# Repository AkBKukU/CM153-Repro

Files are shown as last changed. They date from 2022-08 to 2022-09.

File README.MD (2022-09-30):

# Philips CM-153 LMSI Reproduction Card

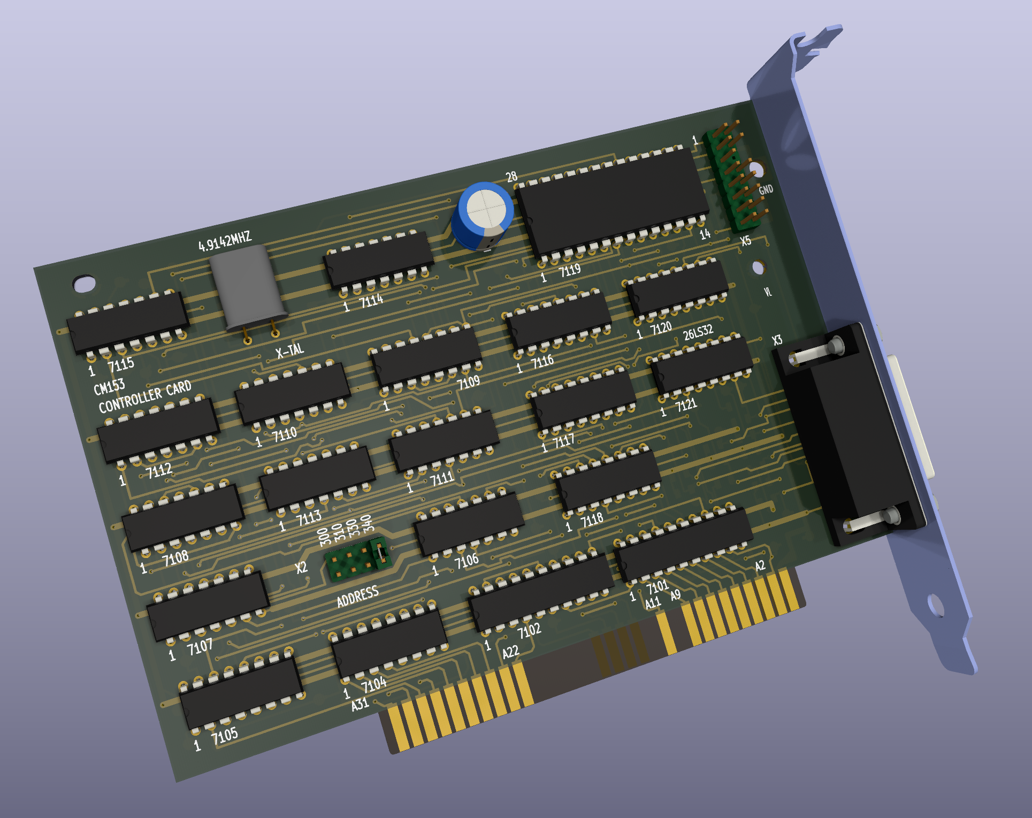
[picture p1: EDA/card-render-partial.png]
A 3d render of the board A render of the clone PCB

 
This project aims to reproduce the LMSI CM-153 card needed to operate a Philips CM-100 CD-ROM drive. This drive was originally released in 1985 and used an early version of the LSMI protocol to connect. Later versions of LMSI cards, such as the CM-260, are not compatible with earlier drives (I do not know what the exactly compatibilities are). So an early card is required. The CM-153 is a very uncommon part to find due to it's limited use, high cost, and the fact that it would probably be tossed out with the computer when upgraded being separated from its original drive.

Thanks to Roland who has a [working CM-100 and CM-153](https://www.youtube.com/watch?v=fj-uSWg0LOY) we have some pretty high quality reference images of what this card looks like. It uses all off the shelf 74 series logic chips and one 8251A UART controller. It should therefore be possible to recreate without needing any rare chips or ROM dumps.

## Current Status

The card has been fully reverse engineered and tested to be functional. It has been demonstrated to work using [this](http://mpolibbs.steptail.com/hardware/CDROM/PHILIPS/CM50DRV.ZIP) driver with a CM100 drive.

## Notes

A more acurate build will put 7121 in a socket as it must be removed to use the card with an internal drive. If you just want to use it with an external drive this can be ommited.

The selected DB-15 connector doesn't include the screw nuts which can be purchased separately.

## Parts List

*(Parts picked on 2022-09-07 and reflected best available stock)*

|RefDes|Original Part Number| Datasheet| Digikey Part| Mouser Part|
--- | --- | ---| ---| ---|
|7101|PC74HCT245P|[Datasheet](https://assets.nexperia.com/documents/data-sheet/74HC_HCT245.pdf)|[CD74HCT245E](https://www.digikey.com/en/products/detail/texas-instruments/CD74HCT245E/38454)|[SN74HCT245NE4](https://www.mouser.com/ProductDetail/Texas-Instruments/SN74HCT245NE4?qs=SL3LIuy2dWzrNeCJprt44g%3D%3D)|
|7102|PC74HCT244P|[Datasheet](https://assets.nexperia.com/documents/data-sheet/74HC_HCT244.pdf)|[CD74HCT244E](https://www.digikey.com/en/products/detail/texas-instruments/CD74HCT244E/38450)|[CD74HCT244E](https://www.mouser.com/ProductDetail/Texas-Instruments/CD74HCT244E?qs=Zu35EjizYSQlHH5t78bA9Q%3D%3D)|
|7104,7105|PC74HCT138P|[Datasheet](https://archive.org/details/74HCT138)|[CD74HCT138E](https://www.digikey.com/en/products/detail/texas-instruments/CD74HCT138E/38262)|[CD74HCT138E](https://www.mouser.com/ProductDetail/Texas-Instruments/CD74HCT138E?qs=IEl3ej0IqwCH%2FZM9hy22Dg%3D%3D)|
|7106|PC74HC08P|[Datasheet](https://archive.org/details/manuallib-id-2654066)|[TC74HC08APF](https://www.digikey.com/en/products/detail/toshiba-semiconductor-and-storage/TC74HC08APF/870461)|[SN74HC08AN](https://www.mouser.com/ProductDetail/Texas-Instruments/SN74HC08AN?qs=byeeYqUIh0O9MyGywGYg%252Bw%3D%3D)|
|7107,7108|PC74HC32P|[Datasheet](https://assets.nexperia.com/documents/data-sheet/74HC_HCT32.pdf)|**!M!**[NTE74HC32](https://www.digikey.com/en/products/detail/nte-electronics-inc/NTE74HC32/11650138)|[SN74HC32N](https://www.mouser.com/ProductDetail/Texas-Instruments/SN74HC32N?qs=tJ5HNKWh3OWs99bm2e8RtQ%3D%3D)|
|7109|PC74HC368P|[Datasheet](https://assets.nexperia.com/documents/data-sheet/74HC_HCT368.pdf)|[SN74HC368N](https://www.digikey.com/en/products/detail/texas-instruments/SN74HC368N/376786)|[SN74HC368N](https://www.mouser.com/ProductDetail/Texas-Instruments/SN74HC368N?qs=7KMwW2o1%252BmQFMEJMMaje4Q%3D%3D)|
|7110|PC74HC04P|[Datasheet](https://assets.nexperia.com/documents/data-sheet/74HC_HCT04.pdf)|[SN74HC04N](https://www.digikey.com/en/products/detail/texas-instruments/SN74HC04N/277212)|[SN74HC04AN](https://www.mouser.com/ProductDetail/Texas-Instruments/SN74HC04AN?qs=byeeYqUIh0N6S9uYkR6RCw%3D%3D)|
|7111|PC74HC125P|[Datasheet](https://assets.nexperia.com/documents/data-sheet/74HC_HCT125.pdf)|[CD74HC125E](https://www.digikey.com/en/products/detail/texas-instruments/CD74HC125E/475901)|[SN74HC125NE4](https://www.mouser.com/ProductDetail/Texas-Instruments/SN74HC125NE4?qs=AgY10sKTvDLokkOrwnzHmA%3D%3D)|
|7112,7113|PC74HC74P|[Datasheet](https://assets.nexperia.com/documents/data-sheet/74HC_HCT74.pdf)|NOT AVAILABLE|[CD74HC74EE4](https://www.mouser.com/ProductDetail/Texas-Instruments/CD74HC74EE4?qs=xFfolx0DHx2A6AZK2ZbvuQ%3D%3D)|
|7114,7115|PC74HC4024P|[Datasheet](https://assets.nexperia.com/documents/data-sheet/74HC4024.pdf)|[CD74HC4024E](https://www.digikey.com/en/products/detail/texas-instruments/CD74HC4024E/376737)|[CD74HC4024E](https://www.mouser.com/ProductDetail/Texas-Instruments/CD74HC4024E?qs=pt%2FIv5r0EPeVxf9RvRS8Kg%3D%3D)|
|7116,7117,7118|MC74HC595AN|[Datasheet](https://assets.nexperia.com/documents/data-sheet/74HC_HCT595.pdf)|[CD74HC595E](https://www.digikey.com/en/products/detail/texas-instruments/CD74HC595E/1507396)|[SN74HC595NE4](https://www.mouser.com/ProductDetail/Texas-Instruments/SN74HC595NE4?qs=AgY10sKTvDK0jki9CKjSwg%3D%3D)|
|7119|P8251A|[Datasheet](http://map.grauw.nl/resources/midi/intel_8251.pdf)|NOT AVAILABLE|NOT AVAILABLE|
|7120|DS26LS31CN|[Datasheet](https://www.ti.com/lit/ds/symlink/am26ls31.pdf)|NOT AVAILABLE|[AM26LS31CN](https://www.mouser.com/ProductDetail/Texas-Instruments/AM26LS31CN?qs=mTHRaKC2c7NO%252BlWH6D4lHg%3D%3D)|
|7121|DS26LS32CN|[Datasheet](https://www.ti.com/lit/ds/symlink/am26ls32am.pdf)|[AM26LS32ACN](https://www.digikey.com/en/products/detail/texas-instruments/AM26LS32ACN/277026)|[AM26LS32ACN](https://www.mouser.com/ProductDetail/Texas-Instruments/AM26LS32ACN?qs=IF4wzcbwb3oK65Lb3k1iHg%3D%3D)|
|X-TAL|4.9152MHz||[MP042](https://www.digikey.com/en/products/detail/cts-frequency-controls/MP042/67676)|[MP042](https://www.mouser.com/ProductDetail/CTS-Electronic-Components/MP042?qs=Mr%252BgrRYddfqYTabPpjTZhQ%3D%3D)|
|Big cap (C9)|50V 10uF||[ECA-1HHG100B](https://www.digikey.com/en/products/detail/panasonic-electronic-components/ECA-1HHG100B/413608)|[ECA-1HHG100B](https://www.mouser.com/ProductDetail/Panasonic/ECA-1HHG100B?qs=86KMePBwEH3eLbQCzM6gng%3D%3D)|
|X5|2x8 pin IDC||2x [826656-2](https://www.digikey.com/en/products/detail/te-connectivity-amp-connectors/826656-2/2276228)|2x [826656-2](https://www.mouser.com/ProductDetail/TE-Connectivity/826656-2?qs=DbJIyW2JsP7yZR%252BsE22lHg%3D%3D)|
|X2|2x4 pin IDC||[826656-2](https://www.digikey.com/en/products/detail/te-connectivity-amp-connectors/826656-2/2276228)|[826656-2](https://www.mouser.com/ProductDetail/TE-Connectivity/826656-2?qs=DbJIyW2JsP7yZR%252BsE22lHg%3D%3D)|
|Y3|15 pin D-Sub||[D15S13B4GX00LF](https://www.digikey.com/en/products/detail/amphenol-cs-fci/D15S13B4GX00LF/1539503)|[D15S13B4GX00LF](https://www.mouser.com/ProductDetail/Amphenol-FCI/D15S13B4GX00LF?qs=V0y2QjpmBGTkGk8fxG40%2FA%3D%3D)|
|C1, C2, C3, C8|100nF||[C1206C104K5RAC7800](https://www.digikey.com/en/products/detail/kemet/C1206C104K5RAC7800/411248)|[C1206C104K5RAC](https://www.mouser.com/ProductDetail/KEMET/C1206C104K5RAC?qs=utjsALNw%2FXTrbYrRGHNW%2Fw%3D%3D)|
|C4|33pF||[885012008020](https://www.digikey.com/en/products/detail/w%C3%BCrth-elektronik/885012008020/5453728)|[885012008020](https://www.mouser.com/ProductDetail/Wurth-Elektronik/885012008020?qs=0KOYDY2FL291ofVgKwDyIQ%3D%3D)|
|C5, C6|14pF||[885012008038](https://www.digikey.com/en/products/detail/w%C3%BCrth-elektronik/885012008038/5453737)|[885012008038](https://www.mouser.com/ProductDetail/Wurth-Elektronik/885012008038?qs=0KOYDY2FL2%252BQ%252BIYq9i7pEA%3D%3D)|
|C7|47pF||[885012008021](https://www.digikey.com/en/products/detail/w%C3%BCrth-elektronik/885012008021/5453729)|[885012008021](https://www.mouser.com/ProductDetail/Wurth-Elektronik/885012008021?qs=0KOYDY2FL2%2F%252Bm93ZHe2ewg%3D%3D)|
|R1|10KΩ||[RMCF1206JT10K0](https://www.digikey.com/en/products/detail/stackpole-electronics-inc/RMCF1206JT10K0/1757427)|[RC1206FR-1310KL](https://www.mouser.com/ProductDetail/YAGEO/RC1206FR-1310KL?qs=sGAEpiMZZMvdGkrng054t8AJgcdMkx7xV9EP%2FUfQrjQ%3D)|
|R2|1MΩ||[HV73V2BTTD105J](https://www.digikey.com/en/products/detail/koa-speer-electronics-inc/HV73V2BTTD105J/11495356)|[RC1206JR-071ML](https://www.mouser.com/ProductDetail/YAGEO/RC1206JR-071ML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)|
|R3|100Ω||[RNCP1206FTD100R](https://www.digikey.com/en/products/detail/stackpole-electronics-inc/RNCP1206FTD100R/2240316)|[RC1206JR-07100RL](https://www.mouser.com/ProductDetail/YAGEO/RC1206JR-07100RL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)|
|R4|1KΩ||[RMCF1206JT1K00](https://www.digikey.com/en/products/detail/stackpole-electronics-inc/RMCF1206JT1K00/1757526)|[RC1206FR-131KL](https://www.mouser.com/ProductDetail/YAGEO/RC1206FR-131KL?qs=sGAEpiMZZMvdGkrng054t8AJgcdMkx7xEX6WAGFcbHI%3D)|
|R5, R6, R7, R8|120Ω||[RMCF1206JT120R](https://www.digikey.com/en/products/detail/stackpole-electronics-inc/RMCF1206JT120R/1757405)|[RC1206FR-07120RL](https://www.mouser.com/ProductDetail/YAGEO/RC1206FR-07120RL?qs=sGAEpiMZZMvdGkrng054t8AJgcdMkx7xHngnO2SPVlk%3D)|
|R10, R12, R14, R16|270Ω||[MCR18ERTJ271](https://www.digikey.com/en/products/detail/rohm-semiconductor/MCR18ERTJ271/2796388)|[RC1206FR-07270RL](https://www.mouser.com/ProductDetail/YAGEO/RC1206FR-07270RL?qs=sGAEpiMZZMvdGkrng054t8AJgcdMkx7xeAVb6tXWI0g%3D)|
|R9, R11, R13, R15|220Ω||[RMCF1206JT220R](https://www.digikey.com/en/products/detail/stackpole-electronics-inc/RMCF1206JT220R/1757377)|[AC1206JR-07220RL](https://www.mouser.com/ProductDetail/YAGEO/AC1206JR-07220RL?qs=sGAEpiMZZMvdGkrng054t7zOzNqIRvGc5GFE1pYUTcM%3D)|
|Card Bracket|Bottom DB15 Cutout||[9200-11](https://www.digikey.com/en/products/detail/keystone-electronics/9200-11/2746684)|[9200-11](https://www.mouser.com/ProductDetail/Keystone-Electronics/9200-11?qs=%252BU2dxLPlMC0AIccOWCwv6Q%3D%3D)|

*All SMD parts 1206 size.*

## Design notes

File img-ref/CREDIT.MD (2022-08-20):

Thank you to Roland who has a [working CM-100 and CM-153](https://www.youtube.com/watch?v=fj-uSWg0LOY) for taking these reference images for determining what the chips and other parts on the card are and how the traces are routed!

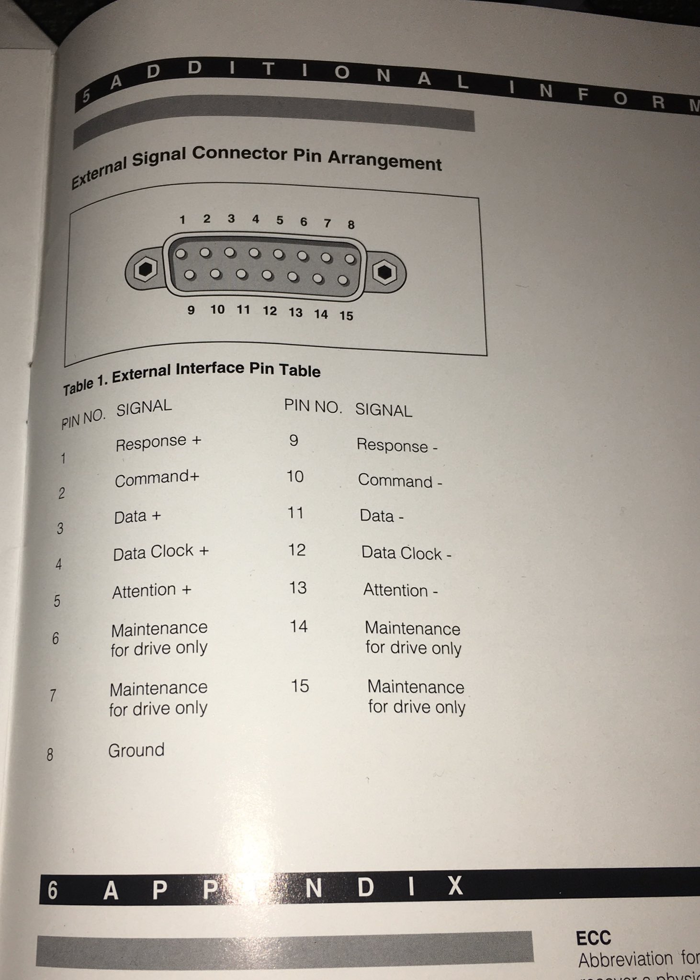
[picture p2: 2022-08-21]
img-ref/LMSI-pinout.jpeg

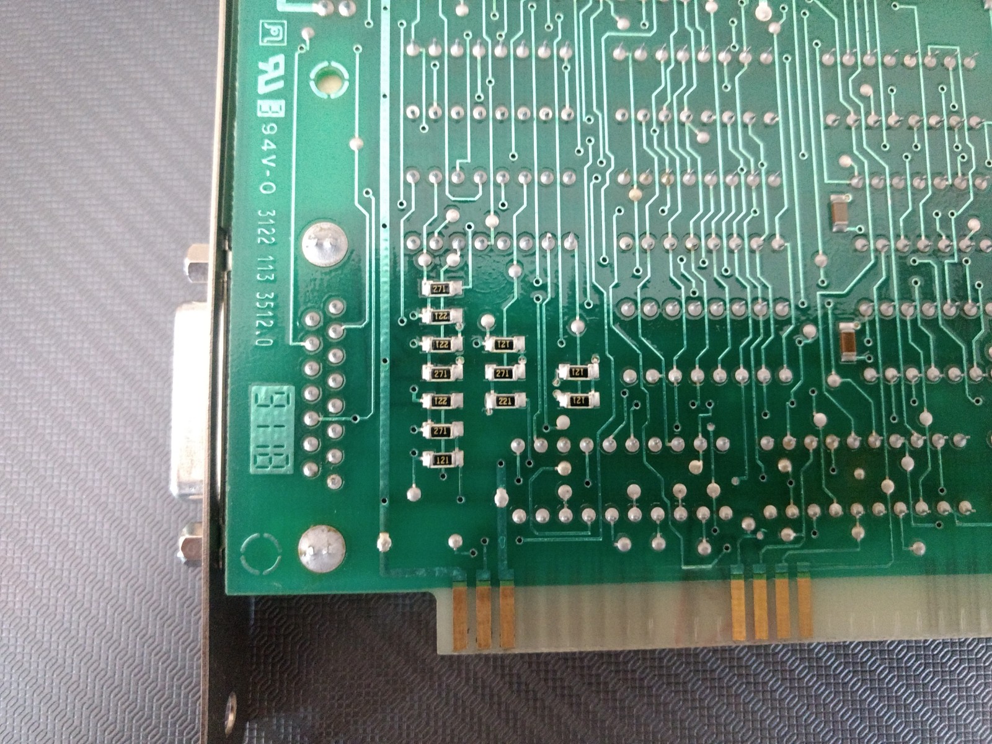
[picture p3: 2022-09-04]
img-ref/diff-rev/resistors.jpeg

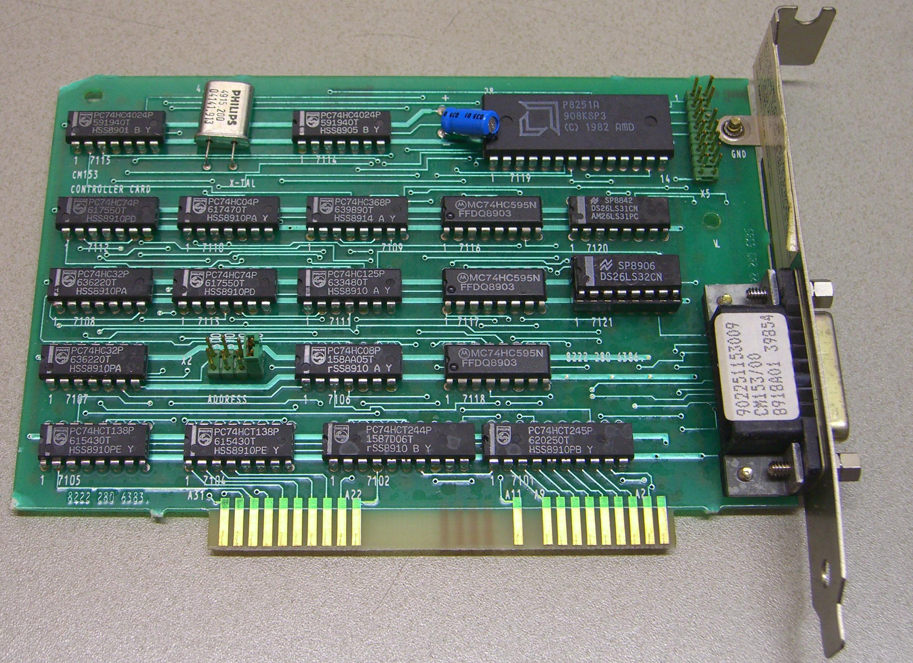
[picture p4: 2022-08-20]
img-ref/CIMG3734.JPG

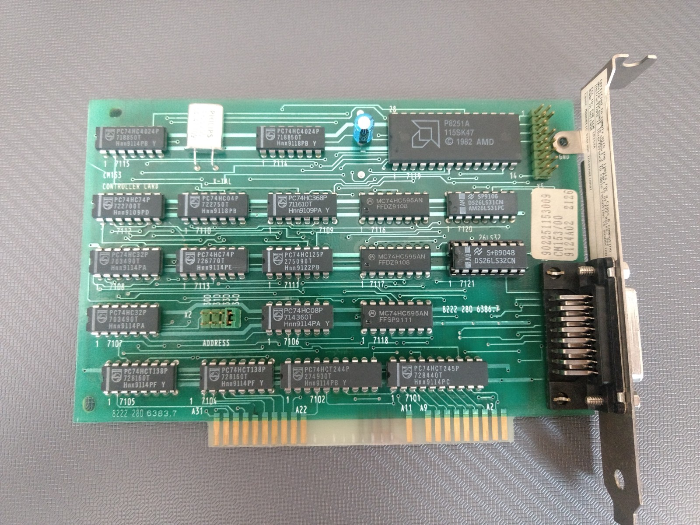
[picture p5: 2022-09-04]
img-ref/diff-rev/front.jpeg

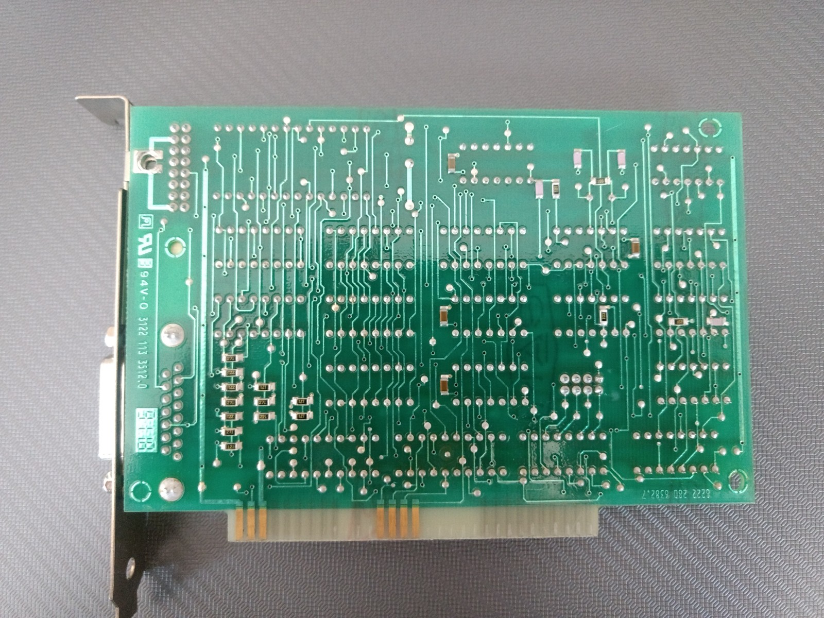
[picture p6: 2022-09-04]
img-ref/diff-rev/bottom.jpeg

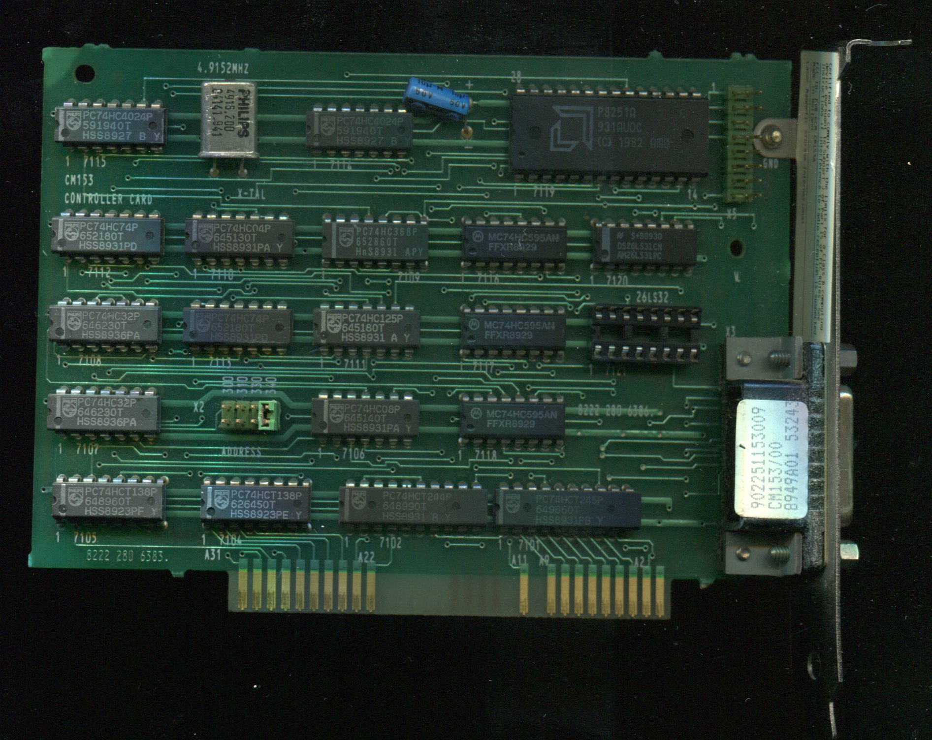
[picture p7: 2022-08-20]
img-ref/Scan 01085.jpg

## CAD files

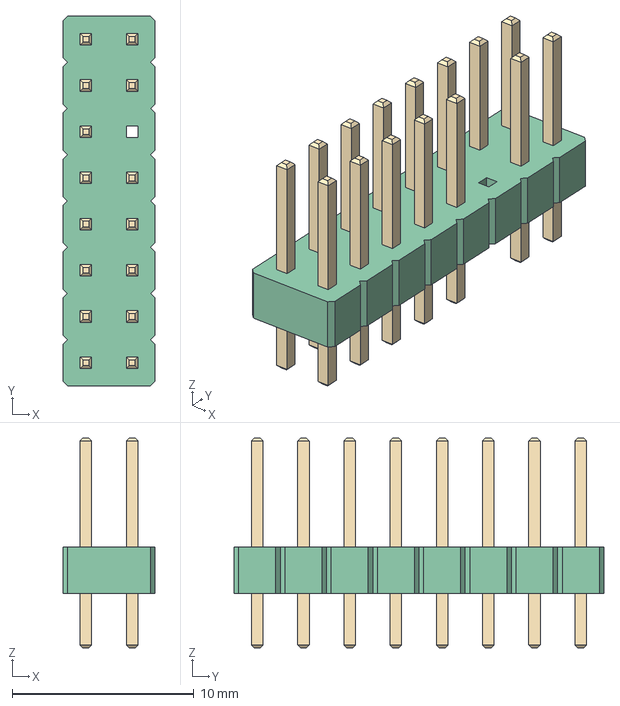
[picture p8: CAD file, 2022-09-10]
EDA/ISA-Card/3d/PinHeader_2x08_P254mm_Vertical_green_missingpin6.step
5.08 x 20.3 x 11.5 mm

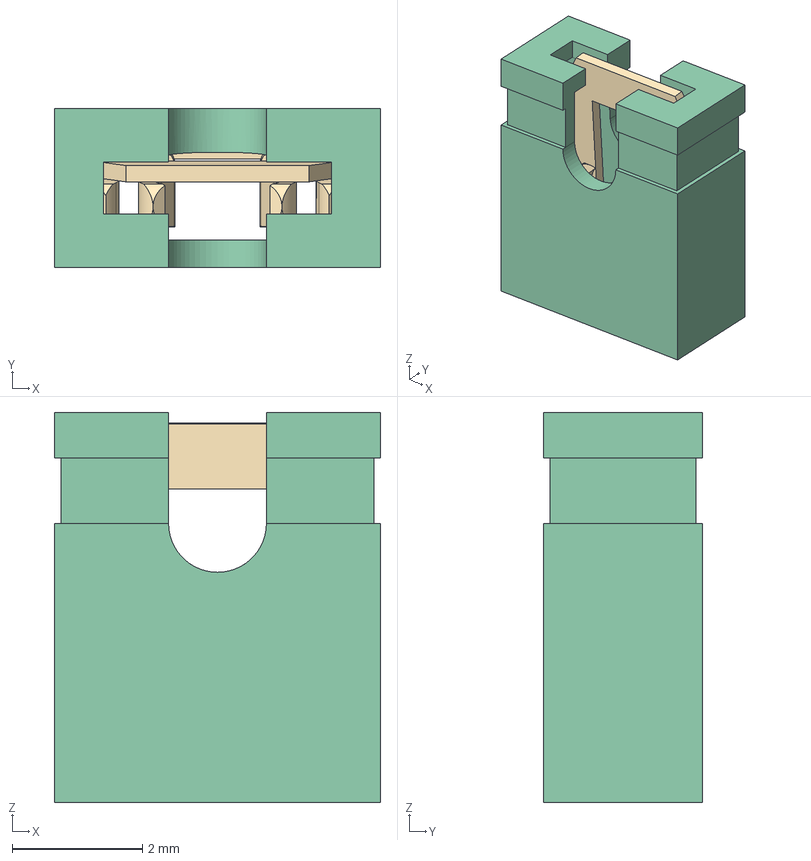
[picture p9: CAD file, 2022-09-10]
EDA/ISA-Card/3d/Jumper_green.step
5.00 x 2.44 x 5.98 mm
Contact
Housing

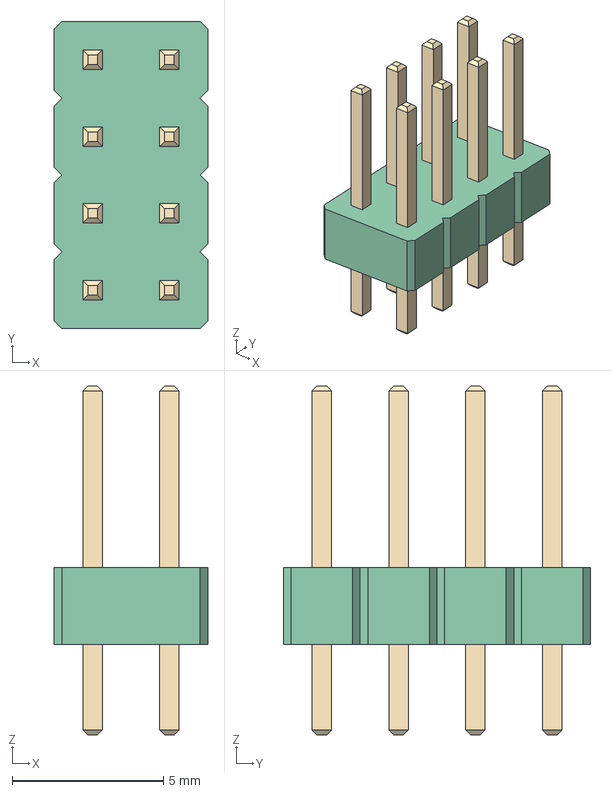
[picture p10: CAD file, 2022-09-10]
EDA/ISA-Card/3d/PinHeader_2x04_P254mm_Vertical_green.step
5.08 x 10.2 x 11.5 mm

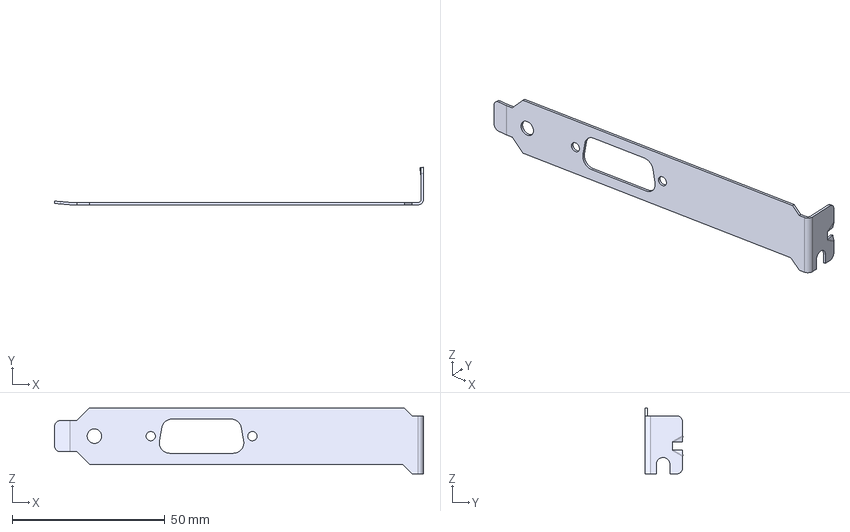
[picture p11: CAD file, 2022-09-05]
EDA/ISA-Card/3d/Custom_CM-153_Bracket.step
120.9 x 12.3 x 21.6 mm

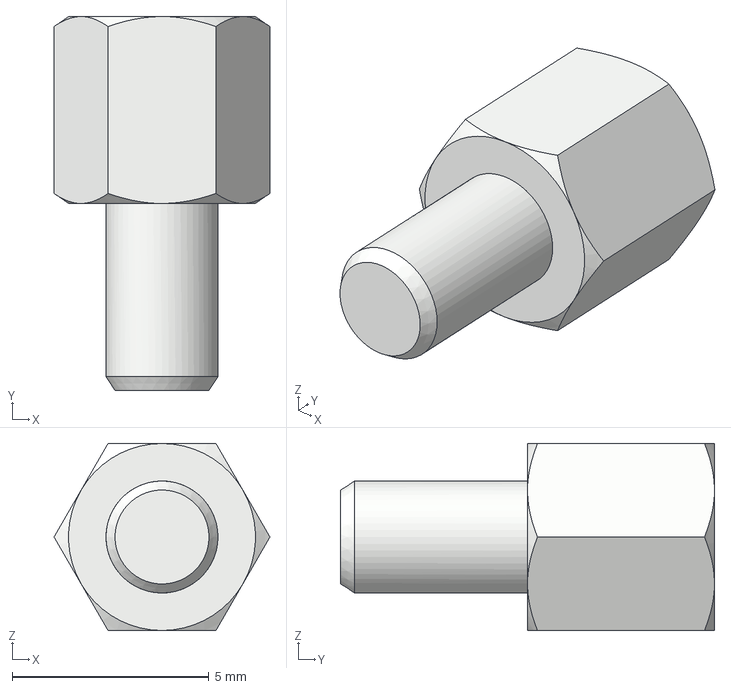
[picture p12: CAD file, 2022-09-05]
EDA/ISA-Card/3d/Keystone_7246_Jack_Screw.step
5.48 x 9.50 x 4.75 mm

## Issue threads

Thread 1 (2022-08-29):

Remaining Objectives Before Getting Boards Made

AkBKukU, 2022-08-29:
#### ~~1. Finish list of point to point checks to make~~
 - Add any traces that go directly under chips that cannot be visually confirmed but make note that they be be inferred from context
#### ~~2. Create footprints for custom shapes used on original board~~
 - Test points
 - Three different mounting holes
 - ISA card edge pads
 - X-tal mounting holes
 - Big Cap silkscreen
#### ~~3. Determine Passive Values~~
 - Add all resistor values from printed codes
 - Caps are likely 100nF for power decoupling, caps near x-tal may need some schematic examples and be based on chosen replacement x-tal part
#### ~~4. Set up proper net classes for traces and determine original trace width~~
 - This may clobber the under chip rails for DRC, copper pours may be used as an alternative
 - Consider also creating custom passive footprint or changing to hand-solder version as originals may be larger
#### ~~5. Fix known differences with original board layout~~
 - GND connection to ISA slot has odd copper shape
 - All traces connecting to passives need adjustment
#### ~~6. Adjust silkscreen~~
 - Refdes locations have not been adjusted at all
 - If possible, hide passive refdes under parts or remove entirely
#### 7. Create Final BOM for Parts Order
 - 8152A and DB-15 connector are the most exotic components and may be more difficult to source
 - Card edge bracket may not mount to PCB or need to be manually cut

#### Bonus
 - Finish schematic refactor based on logical use
 - ~~Create more accurate silkscreen legends to match original~~
 - Recreate part number sticker on inside of bracket

Closed 2022-09-12.

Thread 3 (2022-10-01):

serial capture?

raszpl, 2022-10-01:
Great job!
1/ Now that you have a fully working replica, have you tried capturing and decoding serial stream between drive and controller? Looking at https://twitter.com/andyAVAVsystems/status/1192847018483425280/photo/2
there are 3 serial streams? + clock + attention (irq like?) and 4 mysterious maybe unused pins.  Something like Salea logic clone with 8 bits should be enough. Looking at internal pictures of CM100 it has to be some very basic protocol, I wouldnt be surprised if all it does is sending raw CD data straight from EFM decoder, and the rest is handled in the driver.

2/ Could you post the diagram in pdf/png format so people can readily see it when visiting the repo without downloading/configuring kicad? This would also help with any potential referencing it on the forums. Easier to link someone a png than ask them to install kicad.

ps: I posted links to yt and this repo on https://forum.vcfed.org/index.php?threads/philips-cm100-the-first-cd-rom-found.35616 (post waiting for moderation) as that seemed like the place with highest concentration of people talking about CM100 :)

AkBKukU, 2022-10-01:
1/ It would probably be better to disassemble the driver and work from there to figure out the protocol if someone really wants to. The interface with the 8251 is documented in the datasheets so that wouldn't be hard. That would more likely be complete as well because I wouldn't know how to make the driver send all possible commands to the drive but they would all be in the driver itself.

2/ There is a PDF of the schematic in the folder with the EDA files: https://github.com/AkBKukU/CM153-Repro/blob/main/EDA/ISA-Card/ISA-Card.pdf The gerbers are there as well if someone wants to view the board with a different program as well.

The 1985 drives are prototypes (and absolutely amazing, I want a full height internal CD drive *so bad*) but weren't actually available yet. The RRD-50 was, to the best of my knowledge, the first *released* drive and is the same as the CM100. I intentionally didn't stress the drive too much in the title, or video for that matter, because I don't want it to be confused with the proper video about the CM100 later. If I make the title/thumbnail of this video all about the CM100 and not the card then people might get the later video only about the CM100 confused with this one. And this one seems to be doing fairly well as is so I don't plan on making any changes based on that.

raszpl, 2022-10-01:
You are absolutely right about completeness of the disassembly approach. There are people who prefer to reason about the code, and those who rather measure first to get a five mile high overview :) A glance at LA capture of the traffic would be fascinating and offer immediate general view of the protocol (speed, size of exchanged packets, general data format) without the need to really dig into the code. If nothing else it would make a nice screenshot :) or even separate video.

Im sorry, somehow I missed the pdf :( My brain must of noticed kicad_sch and automatically gave up looking. I would still encourage you to put a direct link to pdf in README.MD above/below parts list. Same goes for link
`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`
to your own video. https://stackoverflow.com/questions/11804820/how-can-i-embed-a-youtube-video-on-github-wiki-pages , bonus points for adding red YT PLAY icon in the middle so its obvious to everyone that its a thumbnail for YT clip.
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

I filly understand not wanting to clickbait, but stating true facts is a good kind of clickbait :). "Rare ISA Card" "Rare CD Drive" arent exactly brain catchy or informative :( sounds more like "obscure", whereas "first ever" "first commercially available" or even just "first" and an actual model "Philips CM-153" are not only factual, but also immediately tells me what I am clicking at. I would hate to try and find link to this video in 5 years in my browsing history.
At least put "Philips CM-153 LMSI Reproduction Card" in the video description. As of now searching for that phase on google /video will not find _your own video_ because there isnt a single mention of "CM-153" or "LMSI" in title/description :(

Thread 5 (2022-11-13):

Adding driver to repo?

makomi, 2022-11-13:
Did you think about adding the [driver](http://mpolibbs.steptail.com/hardware/CDROM/PHILIPS/CM50DRV.ZIP) to this Git repo in case the current source goes offline? It will probably remain available for the next couple of decades, but I think that it will go offline at some point.

ivanvaccari, 2022-12-24:
Got here from youtube video... Not going to use it but to be safe i'll upload it as attachment to this comment.

[CM50DRV.ZIP](https://github.com/AkBKukU/CM153-Repro/files/10298560/CM50DRV.ZIP)

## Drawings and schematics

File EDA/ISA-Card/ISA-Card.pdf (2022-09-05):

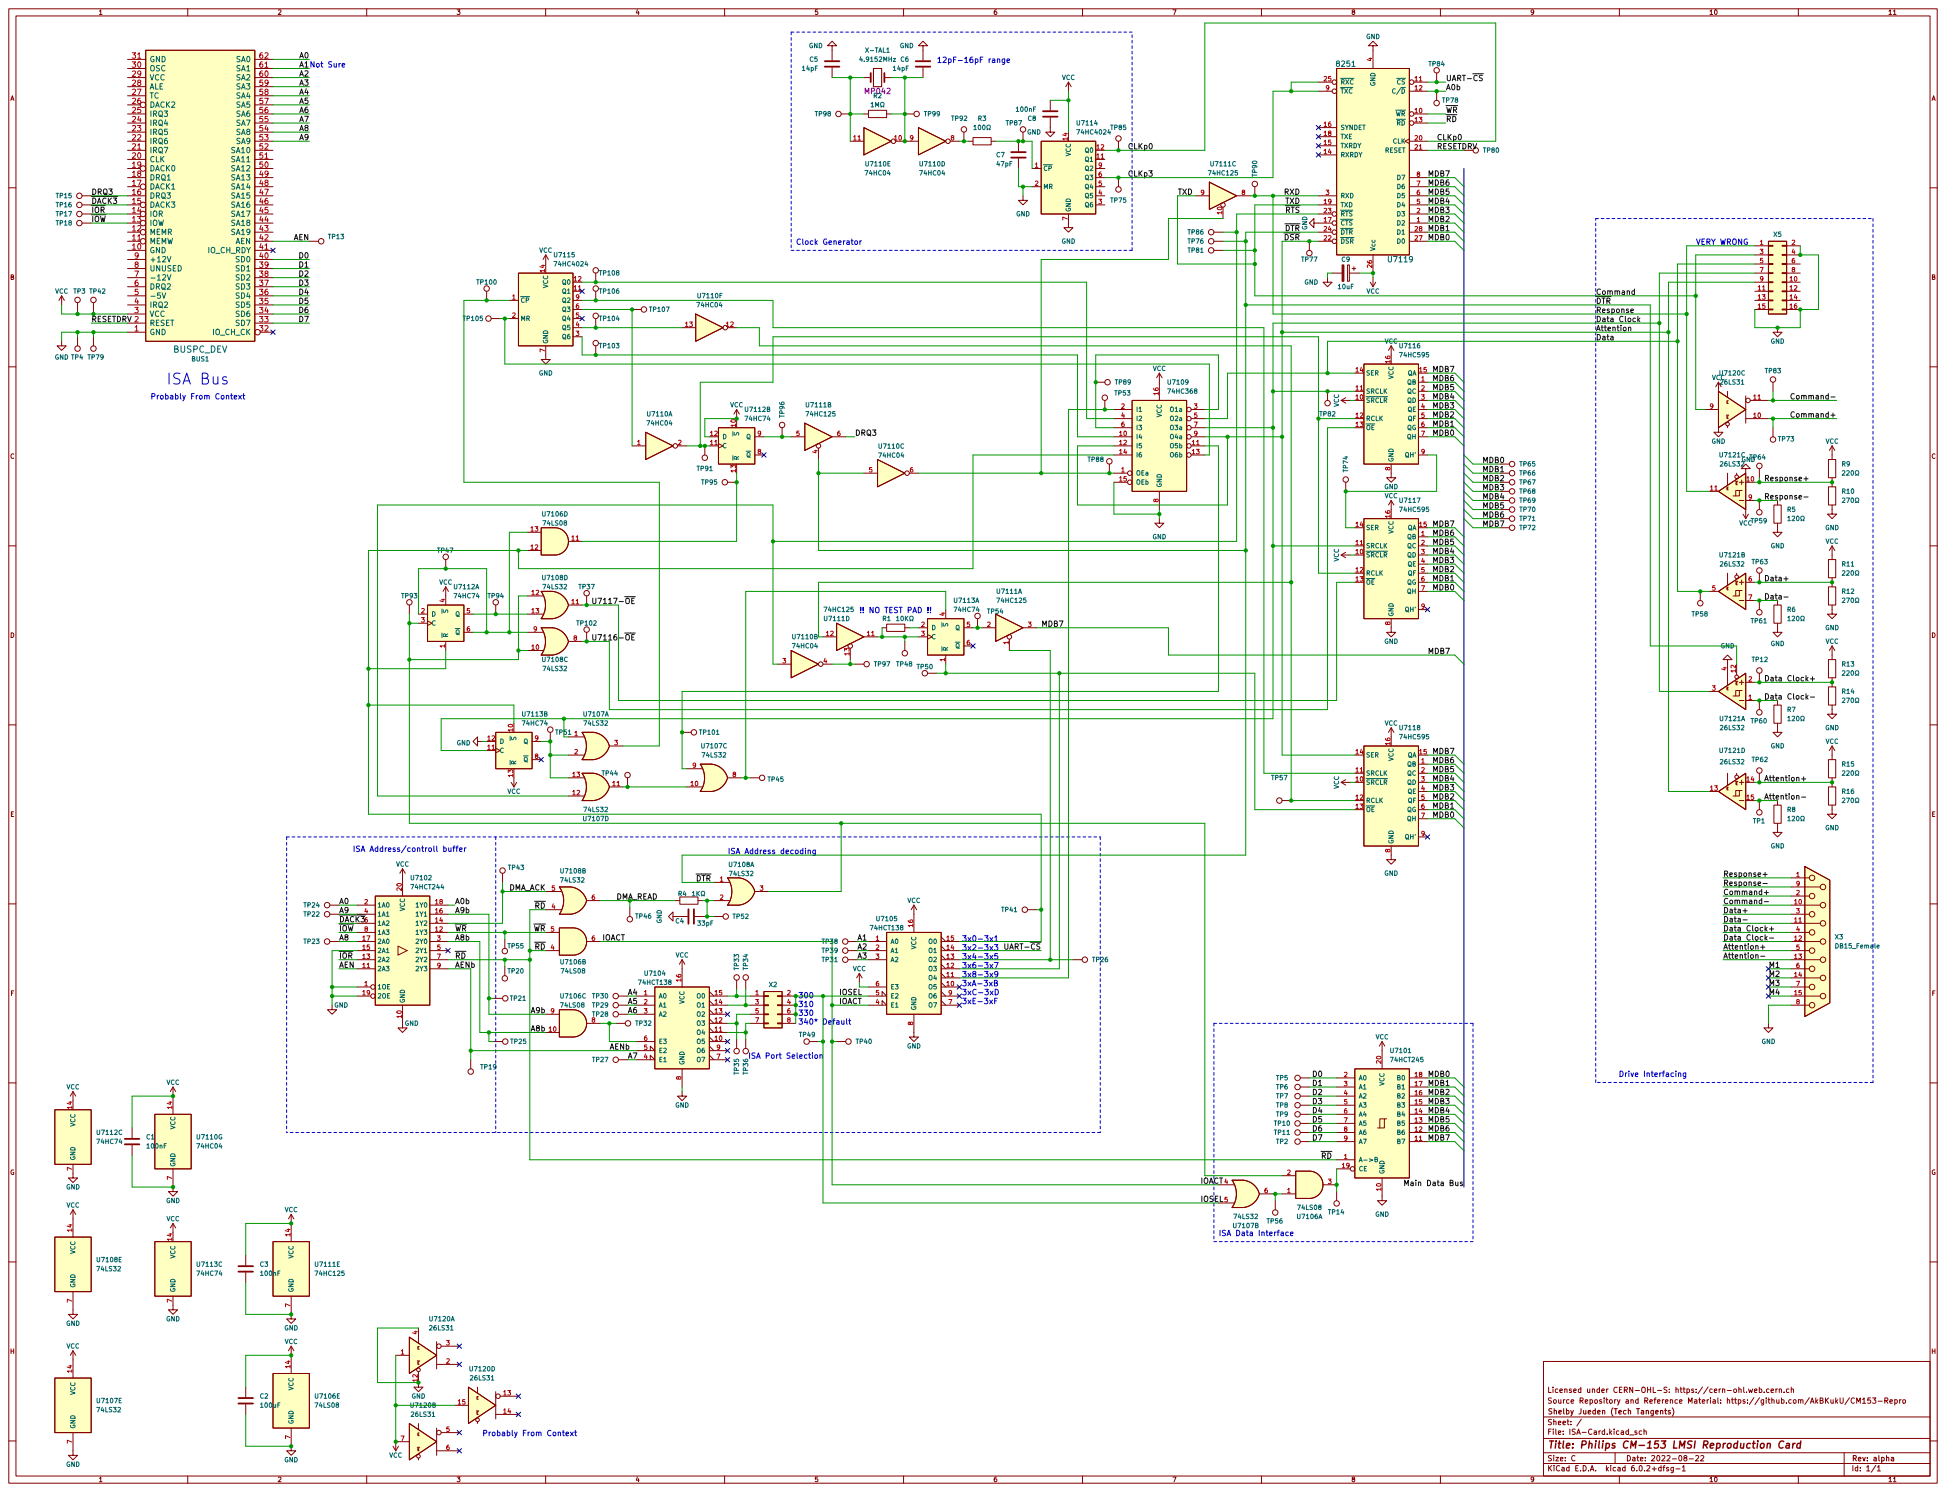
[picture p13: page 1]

ISA Address/controll buffer

Licensed under CERN-OHL-S: https://cern-ohl.web.cern.ch
Source Repository and Reference Material: https://github.com/AkBKukU/CM153-Repro
File: ISA-Card.kicad_sch Sheet: / Shelby Jueden (Tech Tangents)

Id: 1/1 Title: Philips CM-153 LMSI Reproduction Card

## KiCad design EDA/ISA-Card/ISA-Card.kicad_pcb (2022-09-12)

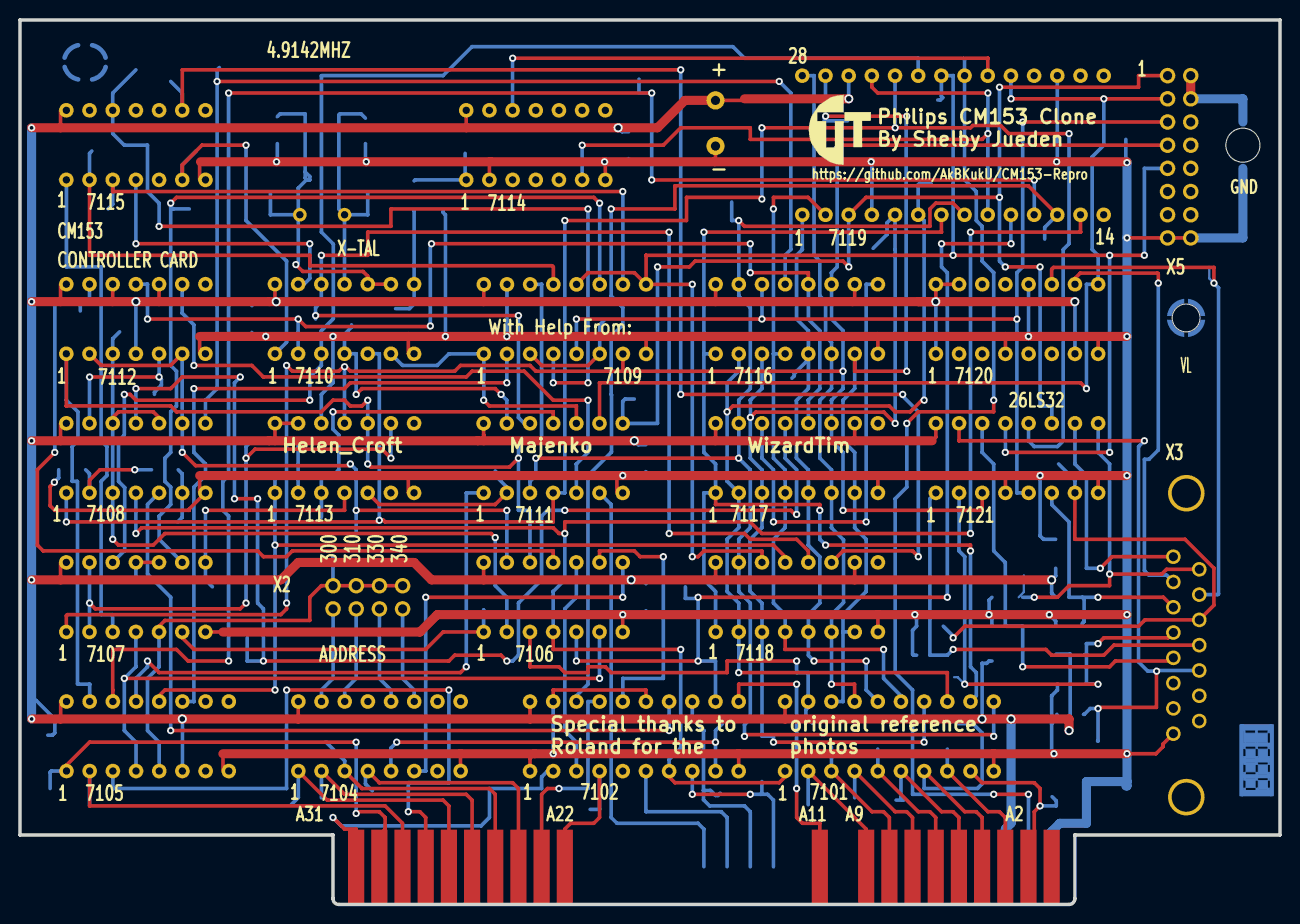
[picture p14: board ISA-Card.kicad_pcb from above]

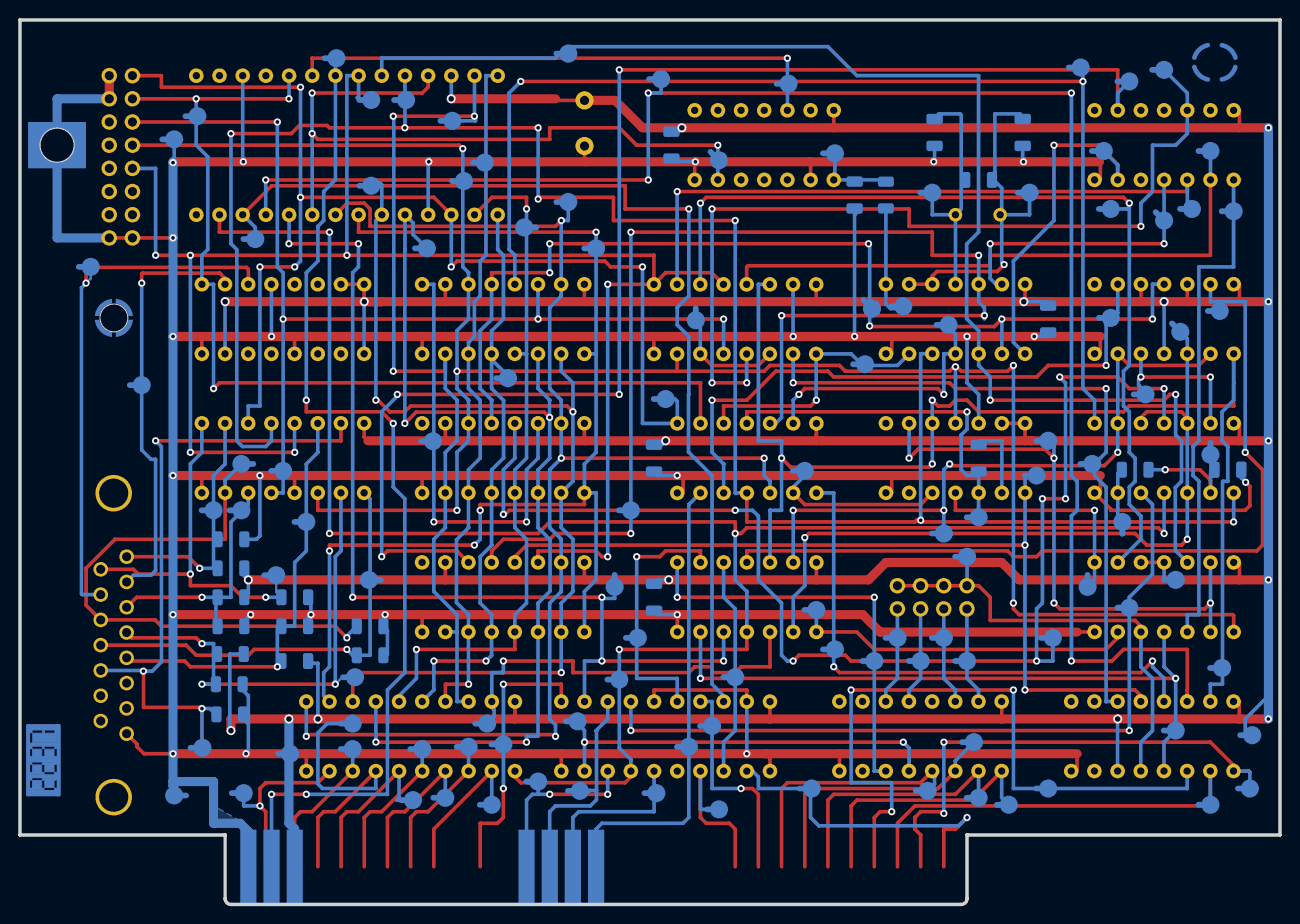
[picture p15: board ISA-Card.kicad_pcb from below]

Board: 2 copper layers, 138.0 x 96.9 mm, 158 parts (24 on the bottom side), 107 nets.

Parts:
7101: 74HCT245; DIP-20_W7.62mm
7102: 74HCT244; DIP-20_W7.62mm
7104, 7105: 74HCT138; DIP-16-Plain
7106: 74LS08; DIP-14-Plain
7107, 7108: 74LS32; DIP-14-Plain
7109: 74HC368; DIP-16-Plain
7110: 74HC04; DIP-14-Plain
7111: 74HC125; DIP-14-Plain
7112, 7113: 74HC74; DIP-14-Plain
7114, 7115: 74HC4024; DIP-14-Plain
7116, 7117, 7118: 74HC595; DIP-16-Plain
7119: 8251; DIP-28_W15.24mm
7120: 26LS31; DIP-16-Plain
7121: 26LS32; DIP-16-Plain
BUS1: BUSPC_DEV; Reduced-ISA
C1, C3, C8: 100nF; C_1206-Clean
C2: 100uF; C_1206-Clean
C4, C7: C; C_1206-Clean
C5, C6: 14pF; C_1206-Clean
C9: 10uF; CP_Radial_D10.0mm_P5.00mm
R1: 10KΩ; R_1206-Clean
R2: 1MΩ; R_1206-Clean
R3: 100Ω; R_1206-Clean
R4: 1KΩ; R_1206-Clean
R5, R6, R7, R8: 120Ω; R_1206-Clean
R9, R11, R13, R15: 220Ω; R_1206-Clean
R10, R12, R14, R16: 270Ω; R_1206-Clean
TP1, TP2, TP3, TP4, TP5, TP6, TP7, TP8, TP9, TP10, TP11, TP12, TP13, TP14, TP15, TP16, TP17, TP18, TP19, TP20, TP21, TP22, TP23, TP24, TP25, TP26, TP27, TP28, TP29, TP30, TP31, TP32, TP33, TP34, TP35, TP36, TP37, TP38, TP39, TP40, TP41, TP42, TP43, TP44, TP45, TP46, TP47, TP48, TP49, TP50, TP51, TP52, TP53, TP54, TP55, TP56, TP57, TP58, TP59, TP60, TP61, TP62, TP63, TP64, TP65, TP66, TP67, TP68, TP69, TP70, TP71, TP72, TP73, TP74, TP75, TP76, TP77, TP78, TP79, TP80, TP81, TP82, TP83, TP84, TP85, TP86, TP87, TP88, TP89, TP90, TP91, TP92, TP93, TP94, TP95, TP96, TP97, TP98, TP99, TP100, TP101, TP102, TP103, TP104, TP105, TP106, TP107, TP108: TestPoint; Test Point
X2: Conn_02x04_Counter_Clockwise; PinHeader_2x04_P2.54mm_Vertical
X3: DB15_Female; DSUB-15_Female_Horizontal_P2.77x2.84mm_EdgePinOffset7.70mm_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
X5: Conn_02x08_Counter_Clockwise; PinHeader_2x08_P2.54mm_Vertical
X-TAL: 4.9152MHz; Crystal_HC49-U_Horizontal

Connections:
/A0: 7102.2 (1A0), BUS1.62 (SA0), TP24.1
/A0b: 7102.18 (1Y0), 7119.12 (C/~D), TP78.1
/A1: 7105.1 (A0), BUS1.61 (SA1), TP38.1
/A2: 7105.2 (A1), BUS1.60 (SA2), TP39.1
/A3: 7105.3 (A2), BUS1.59 (SA3), TP31.1
/A4: 7104.1 (A0), BUS1.58 (SA4), TP30.1
/A5: 7104.2 (A1), BUS1.57 (SA5), TP29.1
/A6: 7104.3 (A2), BUS1.56 (SA6), TP28.1
/A7: 7104.4 (E1), BUS1.55 (SA7), TP27.1
/A8: 7102.17 (2A0), BUS1.54 (SA8), TP23.1
/A8b: 7102.3 (2Y0), 7106.10, TP25.1
/A9: 7102.4 (1A1), BUS1.53 (SA9), TP22.1
/A9b: 7102.16 (1Y1), 7106.9, TP21.1
/AEN: 7102.11 (2A3), BUS1.42 (AEN), TP13.1
/AENb: 7102.9 (2Y3), 7104.5 (E2), TP19.1
/Attention: 7109.9 (O4a), 7109.12 (I5), 7118.14 (SER), 7119.22 (~DSR), 7121.13, TP77.1, X5.9
/Attention+: 7121.14, R15.1, R16.1, TP62.1, X3.5
/Attention-: 7121.15, R8.1, TP1.1, X3.13
/CLKp0: 7114.12 (Q0), 7119.20 (CLK), TP85.1
/CLKp3: 7114.6 (Q3), 7119.9 (~TXC), 7119.25 (~RXC), TP75.1
/Command: 7111.9, 7119.19 (TXD), 7120.9, TP81.1, X5.3
/Command+: 7120.10, TP73.1, X3.2
/Command-: 7120.11, TP83.1, X3.10
/D0: 7101.2 (A0), BUS1.40 (SD0), TP5.1
/D1: 7101.3 (A1), BUS1.39 (SD1), TP6.1
/D2: 7101.4 (A2), BUS1.38 (SD2), TP7.1
/D3: 7101.5 (A3), BUS1.37 (SD3), TP8.1
/D4: 7101.6 (A4), BUS1.36 (SD4), TP9.1
/D5: 7101.7 (A5), BUS1.35 (SD5), TP10.1
/D6: 7101.8 (A6), BUS1.34 (SD6), TP11.1
/D7: 7101.9 (A7), BUS1.33 (SD7), TP2.1
/DMA_ACK: 7102.14 (1Y2), 7108.5, TP43.1
/DMA_READ: 7108.6, R4.2, TP46.1
/DRQ3: 7111.6, BUS1.16 (DRQ3), TP15.1
/Data: 7109.5 (O2a), 7116.14 (SER), 7121.5, TP58.1, X5.5
/Data Clock: 7107.1, 7109.7 (O3a), 7113.11 (C), 7116.11 (SRCLK), 7117.11 (SRCLK), 7121.3, TP82.1, X5.7
/Data Clock+: 7121.2, R13.1, R14.1, TP12.1, X3.4
/Data Clock-: 7121.1, R7.1, TP60.1, X3.12
/Data+: 7121.6, R11.1, R12.1, TP63.1, X3.3
/Data-: 7121.7, R6.1, TP61.1, X3.11 (P111)
/IOACT: 7105.4 (E1), 7106.6, 7107.4, TP40.1
/IOSEL: 7105.5 (E2), 7107.5, TP49.1, X2.2, X2.4, X2.6, X2.8
/MDB0: 7101.18 (B0), 7116.7 (QH), 7117.7 (QH), 7118.7 (QH), 7119.27 (D0), TP65.1
/MDB1: 7101.17 (B1), 7116.6 (QG), 7117.6 (QG), 7118.6 (QG), 7119.28 (D1), TP66.1
/MDB2: 7101.16 (B2), 7116.5 (QF), 7117.5 (QF), 7118.5 (QF), 7119.1 (D2), TP67.1
/MDB3: 7101.15 (B3), 7116.4 (QE), 7117.4 (QE), 7118.4 (QE), 7119.2 (D3), TP68.1
/MDB4: 7101.14 (B4), 7116.3 (QD), 7117.3 (QD), 7118.3 (QD), 7119.5 (D4), TP69.1
/MDB5: 7101.13 (B5), 7116.2 (QC), 7117.2 (QC), 7118.2 (QC), 7119.6 (D5), TP70.1
/MDB6: 7101.12 (B6), 7116.1 (QB), 7117.1 (QB), 7118.1 (QB), 7119.7 (D6), TP71.1
/MDB7: 7101.11 (B7), 7111.3, 7116.15 (QA), 7117.15 (QA), 7118.15 (QA), 7119.8 (D7), TP72.1
/RESETDRV: 7119.21 (RESET), BUS1.2 (RESET), TP80.1
/RXD: 7111.8, 7119.3 (RXD), 7121.11, TP90.1, X5.1
/Response+: 7121.10, R9.1, R10.1, TP64.1, X3.1
/Response-: 7121.9, R5.1, TP59.1, X3.9
/U7116-~OE: 7108.8, 7116.13 (~OE), TP102.1
/U7117-~OE: 7108.11, 7117.13 (~OE), TP37.1
/UART-~CS: 7105.14 (O1), 7119.11 (~CS), TP84.1
/~DACK3: 7102.6 (1A2), BUS1.15 (DACK3), TP16.1
/~DTR: 7108.1, 7110.5, 7111.4, 7119.24 (~DTR), 7121.12, TP76.1
/~IOR: 7102.13 (2A2), BUS1.14 (IOR), TP17.1
/~IOW: 7102.8 (1A3), BUS1.13 (IOW), TP18.1
/~RD: 7101.1 (A->B), 7102.7 (2Y2), 7106.4, 7108.4, 7119.13 (~RD), TP20.1
/~RTS: 7107.12, 7110.3, 7119.23 (~RTS), TP86.1
/~WR: 7102.12 (1Y3), 7106.5, 7119.10 (~WR), TP55.1
GND: 7101.10 (GND), 7102.1 (1OE), 7102.10 (GND), 7102.15 (2A1), 7102.19 (2OE), 7104.8 (GND), 7105.8 (GND), 7106.7 (GND), 7107.7 (GND), 7108.7 (GND), 7109.8 (GND), 7109.15 (OEb), 7110.7 (GND), 7111.7 (GND), 7112.7 (GND), 7113.7 (GND), 7113.12 (D), 7114.2 (MR), 7114.7 (GND), 7115.7 (GND), 7116.8 (GND), 7117.8 (GND), 7118.8 (GND), 7119.4 (GND), 7119.17 (~CTS), 7120.4, 7120.8 (GND), 7120.12, 7121.4, 7121.8 (GND), BUS1.1 (GND), C1.2, C2.2, C3.2, C4.1, C5.1, C6.1, C7.2, C8.1, C9.2, R5.2, R6.2, R7.2, R8.2, R10.2, R12.2, R14.2, R16.2, TP4.1, TP79.1, X3.8, X5.2, X5.4, X5.15, X5.16
unnamed: 7108.2, C4.2, R4.1, TP52.1
unnamed: 7110.11, C5.2, R2.2, TP98.1, X-TAL.1
unnamed: 7110.9, 7110.10, C6.2, R2.1, TP99.1, X-TAL.2
unnamed: 7114.1 (~CP), C7.1, R3.1, TP87.1
unnamed: 7111.11, 7113.3 (C), R1.1, TP48.1
unnamed: 7113.2 (D), R1.2
unnamed: 7110.8, R3.2, TP92.1
unnamed: 7101.19 (CE), 7106.3, TP14.1
unnamed: 7105.13 (O2), 7111.1, TP26.1
unnamed: 7104.6 (E3), 7106.8, TP32.1
unnamed: 7104.15 (O0), TP33.1, X2.1
unnamed: 7104.14 (O1), TP34.1, X2.3
unnamed: 7104.12 (O3), TP35.1, X2.5
unnamed: 7104.11 (O4), TP36.1, X2.7
unnamed: 7105.15 (O0), 7106.12, 7109.14 (I6), 7112.1 (~R), 7113.10 (~S), TP41.1
unnamed: 7107.10, 7107.11, TP44.1
unnamed: 7107.8, 7113.4 (~S), TP45.1
unnamed: 7106.13, 7108.9, 7112.2 (D), 7112.6 (~Q), TP47.1
unnamed: 7105.12 (O3), 7113.1 (~R), 7118.13 (~OE), TP50.1
unnamed: 7107.2, 7107.13, 7113.9 (Q), TP51.1
unnamed: 7105.11 (O4), 7109.2 (I1), TP53.1
unnamed: 7111.2, 7113.5 (Q), TP54.1
unnamed: 7106.1, 7107.6, TP56.1
unnamed: 7110.12, 7111.12, 7118.12 (RCLK), TP57.1
unnamed: 7116.9 (QH'), 7117.14 (SER), TP74.1
unnamed: 7109.1 (OEa), 7110.6, 7111.10, TP88.1
unnamed: 7109.3 (O1a), 7109.6 (I3), TP89.1
unnamed: 7110.2, 7112.11 (C), 7116.12 (RCLK), 7117.12 (RCLK), TP91.1
unnamed: 7106.2, 7108.3, 7108.10, 7108.12, 7112.3 (C), TP93.1
unnamed: 7108.13, 7112.5 (Q), TP94.1
unnamed: 7106.11, 7112.13 (~R), TP95.1
unnamed: 7111.5, 7112.9 (Q), TP96.1
unnamed: 7110.4, 7111.13, TP97.1
unnamed: 7107.3, 7115.1 (~CP), TP100.1
unnamed: 7107.9, 7109.11 (O5b), TP101.1
unnamed: 7109.10 (I4), 7115.3 (Q6), TP103.1
unnamed: 7110.13, 7115.4 (Q5), TP104.1
unnamed: 7109.13 (O6b), 7115.2 (MR), TP105.1
unnamed: 7115.9 (Q2), 7118.11 (SRCLK), TP106.1
unnamed: 7110.1, 7115.6 (Q3), TP107.1
unnamed: 7109.4 (I2), 7115.12 (Q0), TP108.1
VCC: 7101.20 (VCC), 7102.20 (VCC), 7104.16 (VCC), 7105.6 (E3), 7105.16 (VCC), 7106.14 (VCC), 7107.14 (VCC), 7108.14 (VCC), 7109.16 (VCC), 7110.14 (VCC), 7111.14 (VCC), 7112.4 (~S), 7112.10 (~S), 7112.12 (D), 7112.14 (VCC), 7113.13 (~R), 7113.14 (VCC), 7114.14 (VCC), 7115.14 (VCC), 7116.10 (~SRCLR), 7116.16 (VCC), 7117.10 (~SRCLR), 7117.16 (VCC), 7118.10 (~SRCLR), 7118.16 (VCC), 7119.26 (Vcc), 7120.1, 7120.7, 7120.15, 7120.16 (VCC), 7121.16 (VCC), BUS1.3 (VCC), C1.1, C2.1, C3.1, C8.2, C9.1, R9.2, R11.2, R13.2, R15.2, TP3.1, TP42.1

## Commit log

2022-08-20 begining schematic
2022-08-21 more traces
    [ISA-Card.kicad_pcb, ISA-Card.kicad_sch, ISA-Card.sch]
2022-08-21 Label LMSI Connector
    [ISA-Card.kicad_sch]
2022-08-21 More chips finished
    [ISA-Card.kicad_sch]
2022-08-26 Expand schematic
    [ISA-Card.kicad_sch]
2022-08-27 595's done
    [ISA-Card.kicad_sch]
2022-08-27 1711 finished
    [ISA-Card.kicad_sch]
2022-08-27 1713 finished
    [ISA-Card.kicad_sch]
2022-08-27 All but buffer and external connector done
    [ISA-Card.kicad_sch]
2022-08-27 check in with fault in schematic for internal connector pin 1
    [ISA-Card.kicad_sch]
2022-08-28 Schematic done except response signal, PCB started
    [ISA-Card.kicad_pcb, ISA-Card.kicad_sch]
2022-08-28 clean up schematic
    [ISA-Card.kicad_sch]
2022-08-28 PCB Major Progress
    [ISA-Card-B_Mask.gbs, ISA-Card-B_Silkscreen.gbo, ISA-Card-Back.gbl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]
2022-08-28 Add additional PCB image
2022-08-29 PCB Primary Routing finished, except 2 traces
    [ISA-Card-B_Mask.gbs, ISA-Card-B_Silkscreen.gbo, ISA-Card-Back.gbl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]
2022-08-29 Update Schematic PDF
2022-08-29 Connect RCLKs together and update doc
    [ISA-Card-B_Mask.gbs, ISA-Card-B_Silkscreen.gbo, ISA-Card-Back.gbl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]
2022-08-29 Disconnect RCLKs in favor of different idea
    [ISA-Card-B_Mask.gbs, ISA-Card-B_Silkscreen.gbo, ISA-Card-Back.gbl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]
2022-08-31 Mark default port on schematic
    [ISA-Card.kicad_sch]
2022-08-31 Added Philips Custom Mounting Holes
    [ISA-Card.kicad_pcb]
2022-08-31 Added test points
    [ISA-Card-B_Mask.gbs, ISA-Card-B_Silkscreen.gbo, ISA-Card-Back.gbl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]
2022-08-31 Add schematic pdf
2022-08-31 Bring in schematic changes from Helen Croft
    [ISA-Card.kicad_pcb, ISA-Card.kicad_sch]
2022-08-31 Fixed missed connection on 7113 Pin 13
    [ISA-Card.kicad_pcb, ISA-Card.kicad_sch]
2022-08-31 All nets checked and annotated for number of test pads Three nets are missing test pads, though one is connecting a two pins through a resistor and seems harmless. The othersare going to the drive in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
    [ISA-Card.kicad_pcb, ISA-Card.kicad_sch]
2022-09-01 Add extra silk screen markings, not fully acurate though
    [ISA-Card-B_Mask.gbs, ISA-Card-B_Silkscreen.gbo, ISA-Card-Back.gbl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]
2022-09-01 Change unseen traces under UART to connect data clocks and update unsure traces
    [ISA-Card.kicad_pcb, ISA-Card.kicad_sch]
2022-09-01 Removed unused pads from ISA connector
    [ISA-Card.kicad_pcb]
2022-09-01 Export gerbers and PDF
    [ISA-Card-B_Mask.gbs, ISA-Card-B_Silkscreen.gbo, ISA-Card-Back.gbl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]
2022-09-01 Add more schematic cleanup from Helen Croft
    [ISA-Card-B_Mask.gbs, ISA-Card-B_Silkscreen.gbo, ISA-Card-Back.gbl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]
2022-09-01 Connect Response to RXD
    [ISA-Card-B_Mask.gbs, ISA-Card-B_Silkscreen.gbo, ISA-Card-Back.gbl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]
2022-09-01 Connect buffer enable to DTR, PCB is electrically complete for the first time
    [ISA-Card-B_Mask.gbs, ISA-Card-B_Silkscreen.gbo, ISA-Card-Back.gbl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]
2022-09-02 Add more schematic updates from Helen Croft
    [ISA-Card.kicad_sch]
2022-09-02 Change to correct xtal footprint
    [ISA-Card.kicad_pcb, ISA-Card.kicad_sch]
2022-09-02 Clean up remaining footprints
    [ISA-Card.kicad_pcb]
2022-09-02 Final ISA connector
    [ISA-Card-B_Mask.gbs, ISA-Card-B_Silkscreen.gbo, ISA-Card-Back.gbl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]
2022-09-02 Xtal Values
    [ISA-Card.kicad_pcb, ISA-Card.kicad_sch]
2022-09-03 Fix clearance issue between a via and a track
    Increased clearance between via "Net-(TP91-Pad1)" and track "Net-(TP57-Pad1)" (was 0.0975 mm) by moving it down slightly and adjusting traces.
    [ISA-Card.kicad_pcb]
2022-09-03 Remove all unconnected trace stubs
    Removed 9 unconnected trace stubs and cleaned up their parent traces where required.
    [ISA-Card.kicad_pcb]
2022-09-03 Replace GND ISA pin 1 polygon with filled zone
    Use of polygons for traces is strongly discouraged, they are intended for visual use only, replaced with filled zone. Adjusted trace slightly.
    To re-calculate all filled zones on a PCB press "b".
    [ISA-Card.kicad_pcb]
2022-09-03 Moved TestPoint REFDES to User Comments layer
    REFDES for TP72 on B.Silkscreen interferes with C9 pad, no TP markings appear on original PCB so changed TestPoint REFDES to User Comments layer, pushed to all 108 test points on PCB.
    [ISA-Card.kicad_pcb]
2022-09-03 Fix "Bracket Mount" footprint
    Changed "Bracket Mount" footprint to a proper pad instead of multiple polygons on layers and assigned pad to GND net.
    Added DRC exclusions for two GND traces going into bracket mount footprint (too close to NPTH).
    [ISA-Card.kicad_pcb]
2022-09-04 Update PDF and gerbers
    [ISA-Card-B_Mask.gbs, ISA-Card-B_Silkscreen.gbo, ISA-Card-Back.gbl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]
2022-09-04 Added Card bracket with help from Helen Croft and updated main render
    [ISA-Card.kicad_pcb]
2022-09-05 Clean up SMD pad traces, change to hand solder pads to better match, and add missing models
    [Custom_CM-153_Bracket.step, ISA-Card.kicad_pcb, Keystone_7246_Jack_Screw.step]
2022-09-05 All traces increased to 0.4mm minimum
    [ISA-Card.kicad_pcb]
2022-09-05 Final cleanup complete
    [ISA-Card-B_Mask.gbs, ISA-Card-B_Silkscreen.gbo, ISA-Card-Back.gbl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]
2022-09-05 Add attributtions
    [ISA-Card.kicad_pcb]
2022-09-05 Add cap values measured by Roland
    [ISA-Card.kicad_sch]
2022-09-05 Adjust silk
    [ISA-Card.kicad_pcb]
2022-09-05 Updated readme, pdf, & gerbers
    [ISA-Card-B_Mask.gbs, ISA-Card-B_Silkscreen.gbo, ISA-Card-Back.gbl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]
2022-09-05 Spelling is hard
    [ISA-Card-B_Mask.gbs, ISA-Card-B_Silkscreen.gbo, ISA-Card-Back.gbl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]
2022-09-08 minor trace cleanup
    [ISA-Card-B_Mask.gbs, ISA-Card-B_Silkscreen.gbo, ISA-Card-Back.gbl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]
2022-09-08 Add passives (and correct C2)
    [ISA-Card.kicad_sch]
2022-09-09 Added mouser parts and card bracket
    [ISA-Card.kicad_pcb]
2022-09-10 Added new 3d work from Helen_Croft
    [ISA-Card.kicad_pcb, Jumper_green.step, PinHeader_2x04_P254mm_Vertical_green.step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]
2022-09-12 Final checks before production
    [ISA-Card-B_Mask.gbs, ISA-Card-B_Silkscreen.gbo, ISA-Card-Back.gbl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]
